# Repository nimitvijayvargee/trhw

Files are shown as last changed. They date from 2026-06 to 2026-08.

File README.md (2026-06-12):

# this ruler has wifi
(And bluetooth!)

This is an RP2040 ruler that implements wifi, bluetooth, BLE along with a 4MB Flash storage, LEDs, Input buttons and some cool units and lengths!

## Feature list
- wifi
- bluetooth (BT5.2 & BLE)
- 4x RGB Addressable LEDs
- 3x Input buttons
- GPIO output header for more hacky
- Weird units
  - Space Units like Light-picosecond, 10e-18 parsecs and 10e-12 AU
  - The actual wavelength (and quarter wave!) of Bluetooth and Wifi (2.4GHz and - 5GHz)!
- Useful units
  - Inches (down to 0.02 inches!)
  - mm 
  - M2, M2.5 and M3 Diameter holes
  - Length Unit conversion chart
- 4MB QSPI Flash
- Buck-Boost Conversion
- Battery charging and reverse voltage protection.
  - No overcurrent, short circuit or overheating protection!

## Schematic 
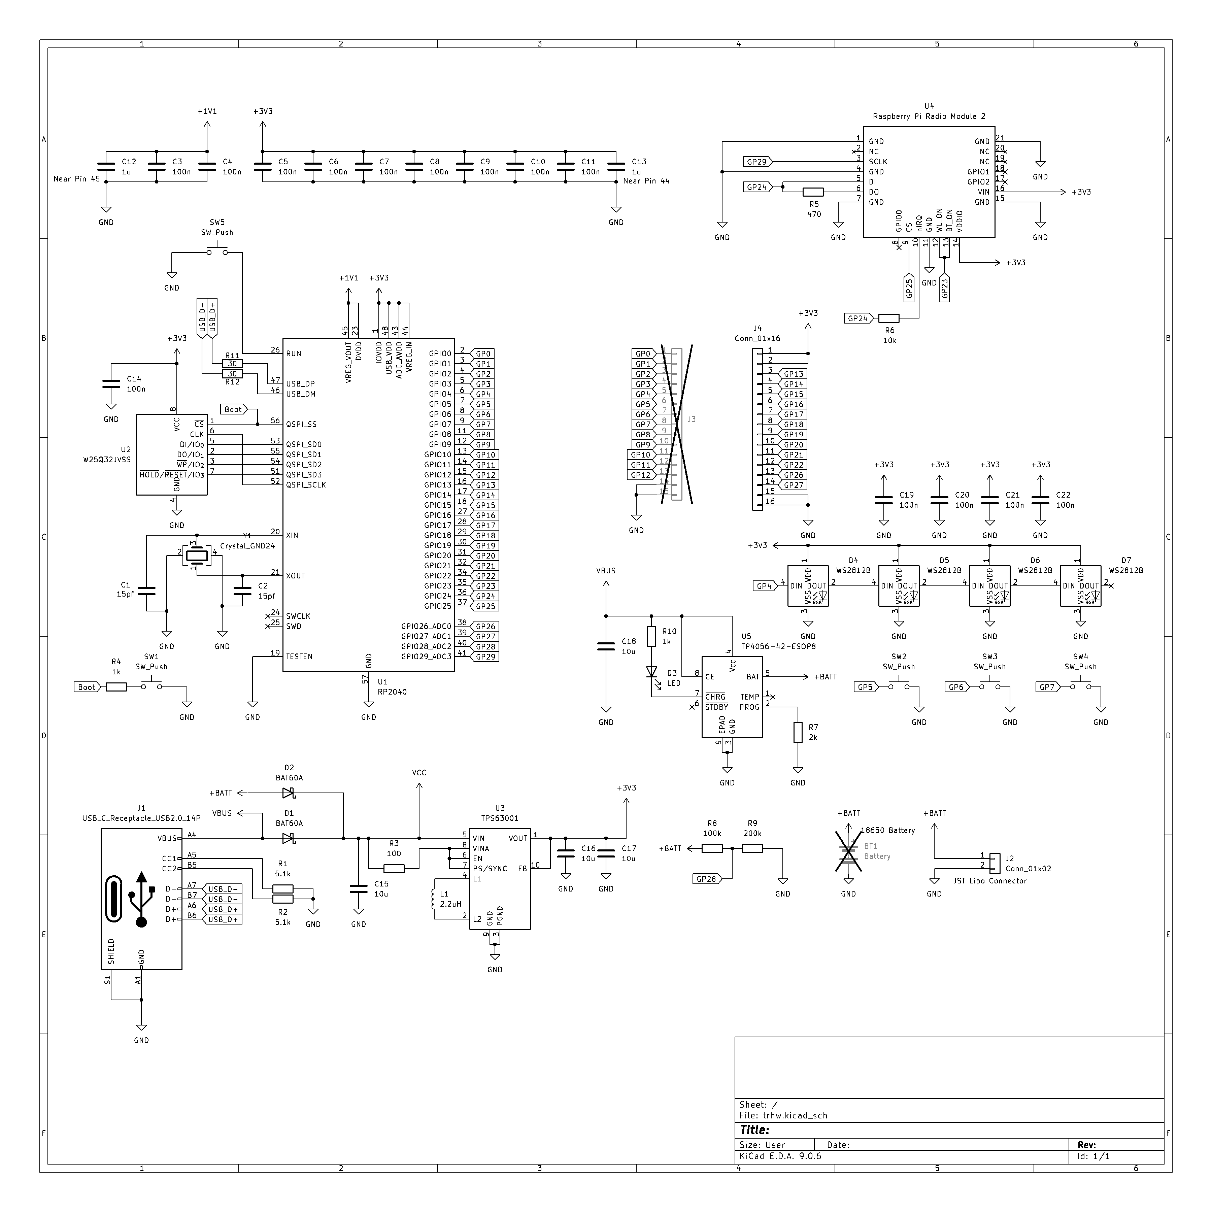
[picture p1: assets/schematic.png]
schematic


## PCB
F.cu
B.cu
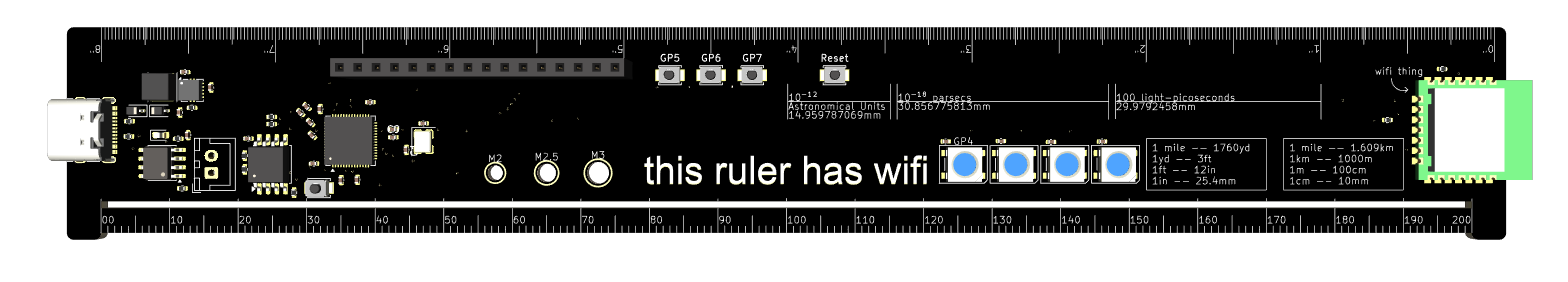
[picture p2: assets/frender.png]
Render (F)

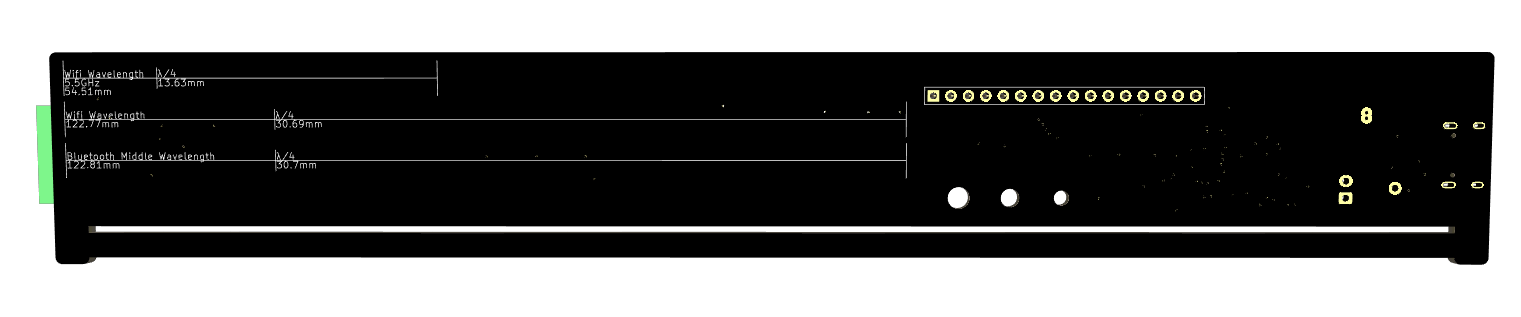
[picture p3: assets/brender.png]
Render (B)


The production files for JLCPCB are included in `PCB/production`

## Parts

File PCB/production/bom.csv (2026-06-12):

Designator | Footprint | Quantity | Value | LCSC Part #
C1, C2 | 0402 | 2 | 15pf
C10, C11, C14, C19, C20, C21, C22, C3, C4, C5, C6, C7, C8, C9 | 0402 | 14 | 100n
C12, C13 | 0402 | 2 | 1u
C15, C16, C17, C18 | 0402 | 4 | 10u
D1, D2 | D_SOD-323 | 2 | BAT60A
D3 | 0603 | 1 | LED
D4, D5, D6, D7 | LED_WS2812B_PLCC4_5.0x5.0mm_P3.2mm | 4 | WS2812B
GP5, GP6, GP7, RESET, SW1 | SW_SPST_B3U-1000P | 5 | SW_Push
J1 | USB_C_Receptacle_G-Switch_GT-USB-7010ASV | 1 | USB_C_Receptacle_USB2.0_14P
J2 | JST_XH_B2B-XH-A_1x02_P2.50mm_Vertical | 1 | Conn_01x02
J4 | PinSocket_1x16_P2.54mm_Vertical | 1 | Conn_01x16
L1 | L_Sunlord_SWPA4020S | 1 | 2.2uH
R1, R2 | 0402 | 2 | 5.1k
R10, R4 | 0402 | 2 | 1k
R11, R12 | 0402 | 2 | 30
R3 | 0402 | 1 | 100
R5 | 0402 | 1 | 470
R6 | 0402 | 1 | 10k
R7 | 0402 | 1 | 2k
R8 | 0402 | 1 | 100k
R9 | 0402 | 1 | 200k
U1 | QFN-56-1EP_7x7mm_P0.4mm_EP3.2x3.2mm | 1 | RP2040
U2 | SOIC-8_5.3x5.3mm_P1.27mm | 1 | W25Q32JVSS
U3 | Texas_DRC0010J_ThermalVias | 1 | TPS63001
U4 | rpi_rmc20452t | 1 | Raspberry Pi Radio Module 2
U5 | SOIC-8-1EP_3.9x4.9mm_P1.27mm_EP2.41x3.3mm_ThermalVias | 1 | TP4056-42-ESOP8
Y1 | Crystal_SMD_Abracon_ABM8G-4Pin_3.2x2.5mm | 1 | Crystal_GND24

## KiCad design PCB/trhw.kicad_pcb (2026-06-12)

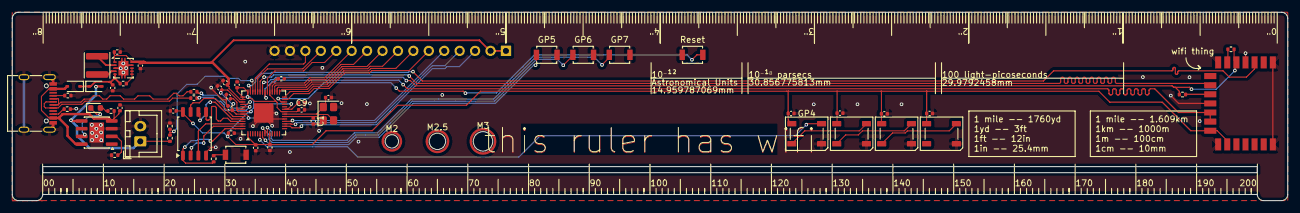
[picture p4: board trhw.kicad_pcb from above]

Board: 2 copper layers, 210.0 x 31.0 mm, 56 parts (0 on the bottom side), 54 nets.

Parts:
C1, C2: 15pf; C_0402_1005Metric
C3, C4, C5, C6, C7, C8, C9, C10, C11, C14, C19, C20, C21, C22: 100n; C_0402_1005Metric
C12, C13: 1u; C_0402_1005Metric
C15, C16, C17, C18: 10u; C_0402_1005Metric
D1, D2: BAT60A; D_SOD-323
D3: LED; LED_0603_1608Metric
D4, D5, D6, D7: WS2812B; LED_WS2812B_PLCC4_5.0x5.0mm_P3.2mm
GP5, GP6, GP7: SW_Push; SW_SPST_B3U-1000P
J1: USB_C_Receptacle_USB2.0_14P; USB_C_Receptacle_G-Switch_GT-USB-7010ASV
J2: Conn_01x02; JST_XH_B2B-XH-A_1x02_P2.50mm_Vertical
J4: Conn_01x16; PinSocket_1x16_P2.54mm_Vertical
L1: 2.2uH; L_Sunlord_SWPA4020S
R1, R2: 5.1k; R_0402_1005Metric
R3: 100; R_0402_1005Metric
R4, R10: 1k; R_0402_1005Metric
R5: 470; R_0402_1005Metric
R6: 10k; R_0402_1005Metric
R7: 2k; R_0402_1005Metric
R8: 100k; R_0402_1005Metric
R9: 200k; R_0402_1005Metric
R11, R12: 30; R_0402_1005Metric
Reset: SW_Push; SW_SPST_B3U-1000P
SW1: SW_Push; SW_SPST_B3U-1000P
U1: RP2040; QFN-56-1EP_7x7mm_P0.4mm_EP3.2x3.2mm
U2: W25Q32JVSS; SOIC-8_5.3x5.3mm_P1.27mm
U3: TPS63001; Texas_DRC0010J_ThermalVias
U4: Raspberry Pi Radio Module 2; rpi_rmc20452t
U5: TP4056-42-ESOP8; SOIC-8-1EP_3.9x4.9mm_P1.27mm_EP2.41x3.3mm_ThermalVias
Y1: Crystal_GND24; Crystal_SMD_Abracon_ABM8G-4Pin_3.2x2.5mm

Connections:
+1V1: C3.1, C4.1, C12.1, U1.23 (DVDD), U1.45 (VREG_VOUT), U1.50 (DVDD)
+3V3: C5.1, C6.1, C7.1, C8.1, C9.1, C10.1, C11.1, C13.1, C14.1, C16.1, C17.1, C19.1, C20.1, C21.1, C22.1, D4.1 (VDD), D5.1 (VDD), D6.1 (VDD), D7.1 (VDD), J4.1, J4.2, U1.1 (IOVDD), U1.10 (IOVDD), U1.22 (IOVDD), U1.33 (IOVDD), U1.42 (IOVDD), U1.43 (ADC_AVDD), U1.44 (VREG_IN), U1.48 (USB_VDD), U1.49 (IOVDD), U2.8 (VCC), U3.1 (VOUT), U3.10 (FB), U4.14 (VDDIO), U4.16 (VIN)
+BATT: D2.2 (A), J2.1, R8.1, U5.5 (BAT)
Boot: R4.1, U1.56 (QSPI_SS), U2.1 (~CS)
GND: C1.2, C2.2, C3.2, C4.2, C5.2, C6.2, C7.2, C8.2, C9.2, C10.2, C11.2, C12.2, C13.2, C14.2, C15.2, C16.2, C17.2, C18.2, C19.2, C20.2, C21.2, C22.2, D4.3 (VSS), D5.3 (VSS), D6.3 (VSS), D7.3 (VSS), GP5.2, GP6.2, GP7.2, J1.A1 (GND), J1.A12 (GND), J1.B1 (GND), J1.B12 (GND), J1.S1 (SHIELD), J2.2, J4.15, J4.16, R1.2, R2.2, R7.2, R9.2, Reset.1, SW1.2, U1.19 (TESTEN), U1.57 (GND), U2.4 (GND), U3.3 (PGND), U3.9 (GND), U3.11 (PGND), U4.1 (GND), U4.4 (GND), U4.7 (GND), U4.11 (GND), U4.15 (GND), U4.21 (GND), U5.3 (GND), U5.9 (EPAD), Y1.2, Y1.4
GP4: D4.4 (DIN), U1.6 (GPIO4)
GP5: GP5.1, U1.7 (GPIO5)
GP6: GP6.1, U1.8 (GPIO6)
GP7: GP7.1, U1.9 (GPIO7)
GP13: J4.3, U1.16 (GPIO13)
GP14: J4.4, U1.17 (GPIO14)
GP15: J4.5, U1.18 (GPIO15)
GP16: J4.6, U1.27 (GPIO16)
GP17: J4.7, U1.28 (GPIO17)
GP18: J4.8, U1.29 (GPIO18)
GP19: J4.9, U1.30 (GPIO19)
GP20: J4.10, U1.31 (GPIO20)
GP21: J4.11, U1.32 (GPIO21)
GP22: J4.12, U1.34 (GPIO22)
GP23: U1.35 (GPIO23), U4.12 (WL_ON), U4.13 (BT_ON)
GP24: R5.1, R6.1, U1.36 (GPIO24), U4.5 (DI)
GP25: U1.37 (GPIO25), U4.9 (CS)
GP26: J4.13, U1.38 (GPIO26_ADC0)
GP27: J4.14, U1.39 (GPIO27_ADC1)
GP28: R8.2, R9.1, U1.40 (GPIO28_ADC2)
GP29: U1.41 (GPIO29_ADC3), U4.3 (SCLK)
unnamed: D3.2 (A), R10.2
unnamed: D3.1 (K), U5.7 (~CHRG)
unnamed: D4.2 (DOUT), D5.4 (DIN)
unnamed: D5.2 (DOUT), D6.4 (DIN)
unnamed: D6.2 (DOUT), D7.4 (DIN)
unnamed: J1.A5 (CC1), R1.1
unnamed: J1.B5 (CC2), R2.1
unnamed: R4.2, SW1.1
unnamed: U1.52 (QSPI_SCLK), U2.6 (CLK)
unnamed: U1.53 (QSPI_SD0), U2.5 (DI/IO_{0})
unnamed: U1.55 (QSPI_SD1), U2.2 (DO/IO_{1})
unnamed: U1.54 (QSPI_SD2), U2.3 (~WP/IO_{2})
unnamed: U1.51 (QSPI_SD3), U2.7 (~HOLD/~RESET/IO_{3})
unnamed: Reset.2, U1.26 (RUN)
unnamed: R12.2, U1.46 (USB_DM)
unnamed: R11.2, U1.47 (USB_DP)
unnamed: C1.1, U1.20 (XIN), Y1.3
unnamed: C2.1, U1.21 (XOUT), Y1.1
unnamed: R3.2, U3.6 (EN), U3.7 (PS/SYNC), U3.8 (VINA)
unnamed: L1.2, U3.4 (L1)
unnamed: L1.1, U3.2 (L2)
unnamed: R5.2, U4.6 (DO)
unnamed: R6.2, U4.10 (nIRQ)
unnamed: R7.1, U5.2 (PROG)
USB_D+: J1.A6 (D+), J1.B6 (D+), R11.1
USB_D-: J1.A7 (D-), J1.B7 (D-), R12.1
VBUS: C18.1, D1.2 (A), J1.A4 (VBUS), J1.A9 (VBUS), J1.B4 (VBUS), J1.B9 (VBUS), R10.1, U5.4 (V_{CC}), U5.8 (CE)
VCC: C15.1, D1.1 (K), D2.1 (K), R3.1, U3.5 (VIN)

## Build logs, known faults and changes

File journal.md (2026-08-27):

This is my log of the work I put into this project, with an estimate of how much time I spent on each step!

### Making the Schematic (3.5hr)
I started making the schematic by referring to the RP2040 Hardware design docs, as well as the docs for the Radio Module 2 and some of the other stuff I used. Most of this time was spent back and forth reading docs, picking ICs and figuring it out. I guess at one point, that's just how all PCBs work huh.

The RP2040 is pretty standard stuff, give it 3.3V, a decent QSPI flash chip and decoupling and it works like a charm. The Radio Module 2 was a bit interesting, but I just ended up following what the docs did word for word, wireless is something I really don't wanna fuck around and find out :/

The Buck/Boost is fun! I put in a TI TPS63001, which gives a nice 3v3 voltage with minimal stuff! I added 2 diodes to prevent backfeeding into USB or the battery, and installed a TP4056 in conjunction with everything else.
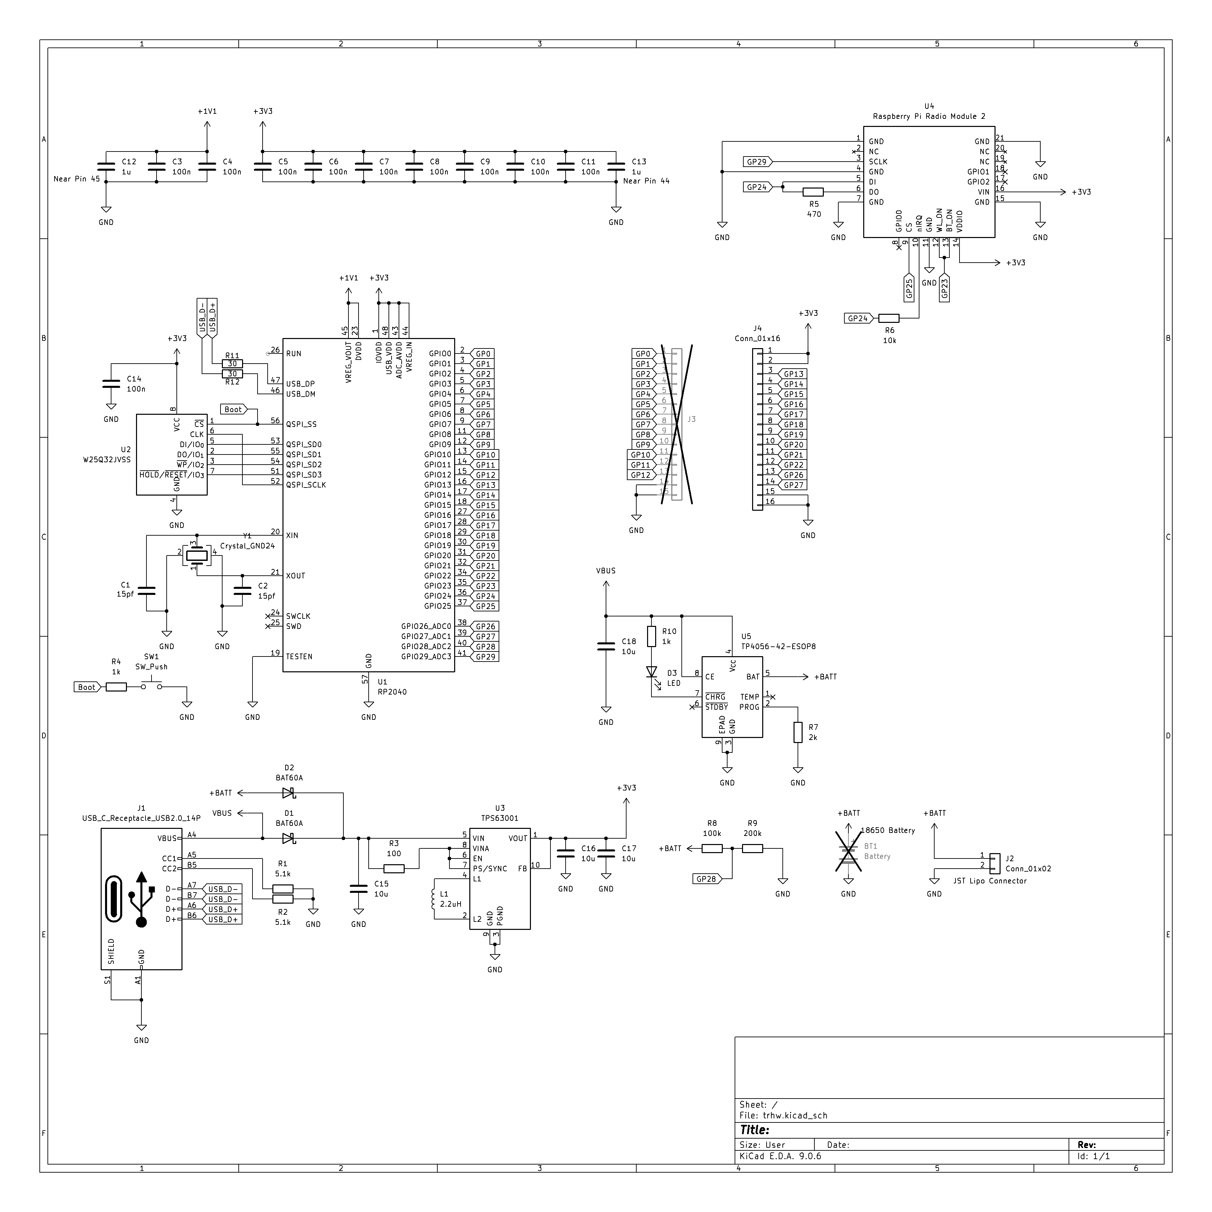
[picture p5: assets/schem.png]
schem


### Starting the PCB (2.5hr)
By this point, making this PCB was quite straightforward as well. I placed all the components and added the components. I shifted the USB C and main mcu to the left side, and the wireless stuff to the right solely because I wanted to keep both on an edge and it would look awkward and unbalanced all together. Routing is pretty easy too. The only things that needed some focus was the USB Differential pair and the QSPI length matching. I got the radio module lengths down to a 10mm difference, which isn't that good but it should be alright :p. I might fix that later though.
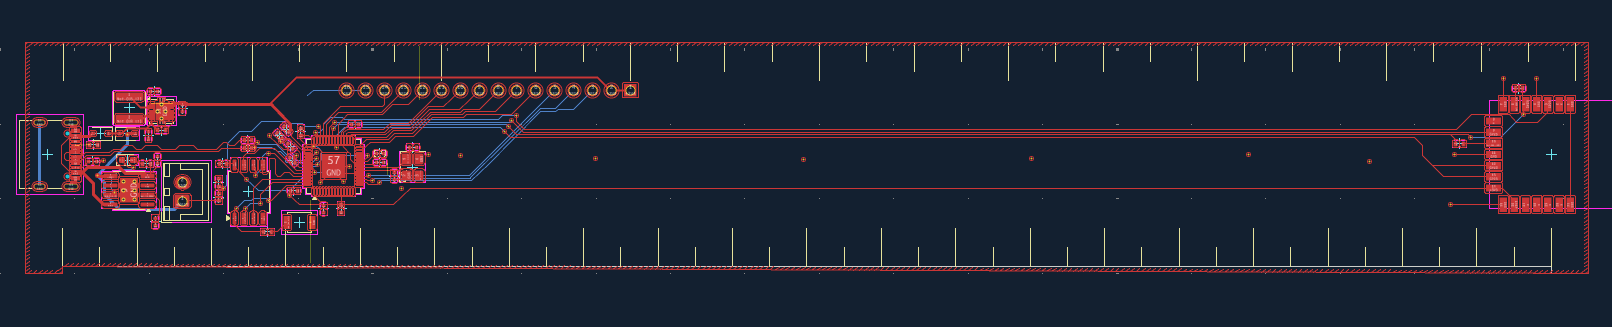
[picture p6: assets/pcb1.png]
PCB1


### Silkscreen! (2hr)
As a ruler, I wanted to pack as many cool units/measurements into the design of it! So, I spent a while finding the best units to put on it while staying practical and hacky. I settled on the Parsec (or at least a quntillionth), 100 light picoseconds (1 was too small, and a nanosecond was too large), and 1 trillionth of an Astronomical Unit (that's the distance from the earth to the sun*) (*t&c apply). I also added the wavelengths (and quarter waves) of the wifi and bluetooth onboard (2.4GHz) and then 5GHz Wifi too.

I also finally added the ticks to the scale of the ruler. For the metric side, I just put a tick every 1mm, and then every 0.02 inches on the imperial side.
I also then added a length conversion table!



### PCB fixes (2hr)
I then ran DRC a few times, fixed my mismatched trace widths, ran DRC, fixed more stuff, etc. I also ended up redoing the signal routing for the radio module chip, since I guess the length matching was real bad. This time around, I got it down to less than 1mm on a 175mm routed length! I also changed the hole footprints on the heat pads of the buck-boost and charging module because hole size limitations. 




Using the empty space I had, it was a nice idea to add a few buttons and LEDs, so I added 4 WS2812B 5050 LEDs and 3 buttons! Fortunately, no more DRC errors from this addition, but the Edge cuts were malformed (classic edge cuts). Fixed those, and I should be done now!

After this, I also added a reset button, since I am already adding like 4 buttons for the GPIO and boot selection :p


I worked on this repo for an hour after this, and I have now completed this project! 

You can find the final PCB, schematic and design in the README



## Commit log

2026-06-07 stuff 2
    [trhw.kicad_pcb, trhw.kicad_sch]
2026-06-08 fix journal
    [trhw.kicad_pcb]
2026-06-08 fix PCB lock files
2026-06-12 Thermal via fix
    [trhw.kicad_pcb]
2026-06-12 Production Files
    [bom.csv, designators.csv, positions.csv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]
